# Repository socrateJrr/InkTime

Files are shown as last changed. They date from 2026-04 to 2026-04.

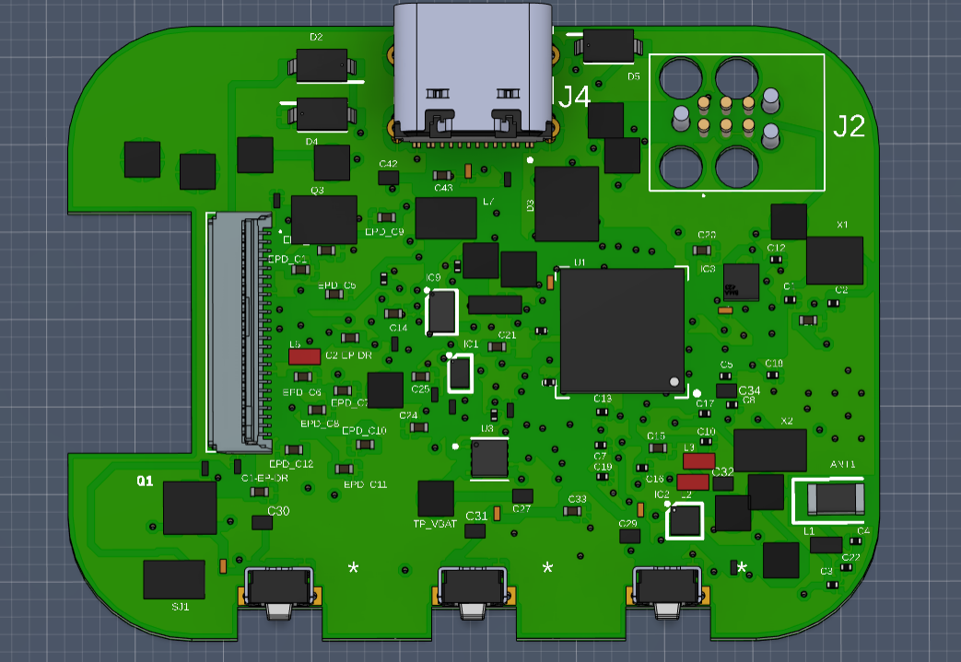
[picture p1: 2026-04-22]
Images/pcb2.png

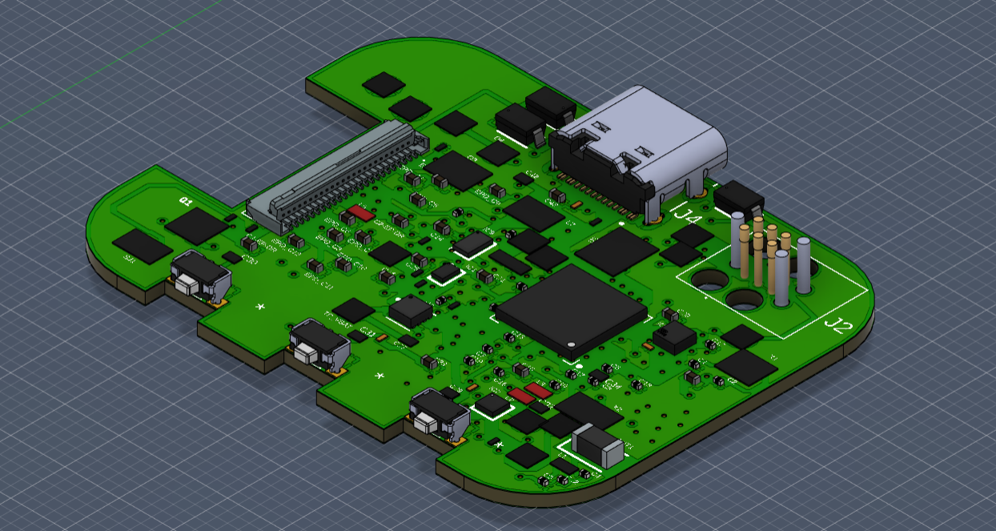
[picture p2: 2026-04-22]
Images/pcb1.png

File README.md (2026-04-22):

# InkTime Smartwatch — PCB Design

InkTime este un smartwatch open-source si low-cost, cu ecran e-paper.

## Diagrama bloc



## BOM (Bill of Materials)

| Referinta | Componenta | Descriere | JLC Parts | Datasheet |
| --- | --- | --- | --- | --- |
| U1 | nRF52840-QIAA | MCU principal BLE 5.0 | [JLC](https://jlcpcb.com/parts/componentSearch?searchTxt=nRF52840) | [Datasheet](https://infocenter.nordicsemi.com/pdf/nRF52840_PS_v1.7.pdf) |
| IC9 | RT6160AWSC | DC/DC Buck-Boost 3.3V | [JLC](https://jlcpcb.com/parts/componentSearch?searchTxt=RT6160AWSC) | [Datasheet](https://www.richtek.com/assets/product_file/RT6160A/DS6160A-00.pdf) |
| IC1 | BQ25180YBGR | LiPo Charger | [JLC](https://jlcpcb.com/parts/componentSearch?searchTxt=BQ25180) | [Datasheet](https://www.ti.com/lit/ds/symlink/bq25180.pdf) |
| U3 | MAX17048G+T10 | Fuel Gauge I2C | [JLC](https://jlcpcb.com/parts/componentSearch?searchTxt=MAX17048G) | [Datasheet](https://datasheets.maximintegrated.com/en/ds/MAX17048-MAX17049.pdf) |
| IC3 | BMA421 | IMU Accelerometru 3 axe | [JLC](https://jlcpcb.com/parts/componentSearch?searchTxt=BMA421) | [Datasheet](https://www.bosch-sensortec.com/media/boschsensortec/downloads/datasheets/bst-bma421-ds000.pdf) |
| IC2 | DRV2605YZFR | Haptic Driver I2C | [JLC](https://jlcpcb.com/parts/componentSearch?searchTxt=DRV2605) | [Datasheet](https://www.ti.com/lit/ds/symlink/drv2605.pdf) |
| ANT1 | 2450AT18B100E | Antena Bluetooth 2.4GHz | [JLC](https://jlcpcb.com/parts/componentSearch?searchTxt=2450AT18B100E) | [Datasheet](https://www.johansontechnology.com/datasheets/2450AT18B100E/2450AT18B100E.pdf) |
| J1 | 503480-2400 | Conector display e-paper 24 pini | [JLC](https://jlcpcb.com/parts/componentSearch?searchTxt=503480-2400) | [Datasheet](https://www.molex.com/pdm_docs/sd/5034802400_sd.pdf) |
| J4 | KH-TYPE-C-16P | Conector USB-C 16 pini | [JLC](https://jlcpcb.com/parts/componentSearch?searchTxt=KH-TYPE-C-16P) | - |
| D3 | USBLC6-2SC6Y | Protectie ESD USB | [JLC](https://jlcpcb.com/parts/componentSearch?searchTxt=USBLC6-2SC6Y) | [Datasheet](https://www.st.com/resource/en/datasheet/usblc6-2.pdf) |
| D2, D4, D5 | MBR0530 | Dioda Schottky | [JLC](https://jlcpcb.com/parts/componentSearch?searchTxt=MBR0530) | [Datasheet](https://www.onsemi.com/pdf/datasheet/mbr0530-d.pdf) |
| J2 | TC2030-IDC | Conector SWD Tag-Connect | [JLC](https://jlcpcb.com/parts/componentSearch?searchTxt=TC2030) | [Datasheet](https://www.tag-connect.com/wp-content/uploads/bsk-pdf-manager/TC2030-IDC_1.pdf) |
| X1 | Crystal 32MHz | Cristal principal MCU | [JLC](https://jlcpcb.com/parts/componentSearch?searchTxt=32MHz+crystal+3225) | - |
| X2 | Crystal 32.768kHz | Cristal RTC | [JLC](https://jlcpcb.com/parts/componentSearch?searchTxt=32768+crystal) | - |
| L7 | FTC252012SR47MBCA | Inductor 0.47uH DC/DC | [JLC](https://jlcpcb.com/parts/componentSearch?searchTxt=FTC252012SR47) | - |
| L5 | Inductor 68uH | Inductor e-paper drive | [JLC](https://jlcpcb.com/parts/componentSearch?searchTxt=68uH+inductor) | - |
| L1 | Inductor 3.9nH | Inductor RF matching | [JLC](https://jlcpcb.com/parts/componentSearch?searchTxt=3.9nH+inductor) | - |
| L2 | Inductor 15nH | Inductor RF | [JLC](https://jlcpcb.com/parts/componentSearch?searchTxt=15nH+inductor) | - |
| L3 | Inductor 10uH | Inductor DC/DC | [JLC](https://jlcpcb.com/parts/componentSearch?searchTxt=10uH+inductor+0402) | - |
| Q1 | DMG2305UX-7 | MOSFET P-channel e-paper | [JLC](https://jlcpcb.com/parts/componentSearch?searchTxt=DMG2305UX) | [Datasheet](https://www.diodes.com/assets/Datasheets/DMG2305UX.pdf) |
| Q3 | SI1308EDL-T1-GE3 | MOSFET N-channel e-paper | [JLC](https://jlcpcb.com/parts/componentSearch?searchTxt=SI1308EDL) | [Datasheet](https://www.vishay.com/docs/71509/si1308edl.pdf) |
| SW_UP/DN/ENT | Butoane tactile SMD | 3 butoane fizice | [JLC](https://jlcpcb.com/parts/componentSearch?searchTxt=tactile+button+smd) | - |
| R*, C* | Rezistente/Condensatoare | Diverse valori pasive | [JLC](https://jlcpcb.com/parts) | - |

---

## Descrierea functionalitatii hardware

### Microcontroller — nRF52840 (U1)

Nucleul dispozitivului este **nRF52840** de la Nordic Semiconductor, un SoC cu procesor ARM Cortex-M4 la 64MHz si BLE 5.0 integrat. Acesta coordoneaza toate perifericele prin interfetele SPI, I2C si GPIO.

Antena externa **ANT1** (2450AT18B100E) este o antena ceramica de 2.4GHz plasata la marginea dreapta a placii. Sub antena exista un decupaj in PCB pentru a maximiza performanta RF — FR4-ul absoarbe semnalul daca antena sta direct pe el. Circuitul de adaptare RF include inductorii L1 (3.9nH), L2 (15nH) si condensatoarele C3, C4, C22.

**Interfete folosite:**

- **SPI** → display e-paper (J1): MOSI, SCK, CS, DC, RST, BUSY
- **I2C** → IMU (IC3), charger (IC1), haptic (IC2), fuel gauge (U3), DC/DC (IC9)
- **USB** → D+/D- prin protectie ESD D3
- **SWD** → programare/debug prin J2 (TC2030-IDC)
- **GPIO** → butoane, intreruperi IMU, HAPTIC_EN

### Alimentare

**IC1 (BQ25180YBGR)** — charger LiPo care preia alimentarea de la USB-C si incarca bateria. Comunica cu MCU prin I2C pentru statusul incarcarii.

**IC9 (RT6160AWSC)** — DC/DC buck-boost converter care genereaza **3.3V stabil** din tensiunea bateriei (3V–4.2V). Inductorul L7 (0.47uH) face parte din circuitul de comutare. Condensatoarele C23, C24 filtreaza intrarea si C25, C33 iesirea.

**U3 (MAX17048G+T10)** — fuel gauge care monitorizeaza nivelul bateriei prin I2C si trimite o intrerupere (ALERT) la nRF cand bateria scade sub un prag configurat.

Bateria se conecteaza direct la test pad-urile **TP_VBAT** si **TP_BAT_GND** (fara conector JST) pentru economisire de spatiu.

### Display e-paper — J1 (503480-2400)

Conector FFC ZIF cu 24 de pini. Circuitul de drive include Q3, Q1, L5 (68uH), D2, D4, D5 si condensatoarele EPD_C1...C12. Comunicatie prin **SPI** + GPIO de control.

### IMU — BMA421 (IC3)

Accelerometru triaxial Bosch conectat prin **I2C**. Folosit pentru wake-on-wrist, pedometru si detectie orientare. Intreruperile IMU_INT1/INT2 sunt conectate la GPIO-uri dedicate ale nRF.

### Haptic — DRV2605YZFR (IC2)

Driver de motor haptic controlat prin **I2C**, activat prin **HAPTIC_EN**. Suporta efecte LRA si ERM din biblioteca interna de 123 efecte.

### USB-C — KH-TYPE-C-16P (J4)

Conector USB-C cu protectie ESD asigurata de D3 (USBLC6-2SC6Y). R1_USB si R2_USB (5K1) pe pinii CC1/CC2 pentru detectia cablului USB.

### Programare SWD — TC2030-IDC (J2)

Conector Tag-Connect 6 pini pentru programare si debug SWD. Semnale: SWDIO, SWDCLK, RESET, SWO, 3.3V, GND.

---

## Pinii nRF52840 folositi

| Pin nRF52840  | Semnal | Componenta | Functie |
| --- | --- | --- | --- |
| P0.00 (XL1) | XL1 | X1 (32MHz) | Cristal principal — clock MCU |
| P0.01 (XL2) | XL2 | X1 (32MHz) | Cristal principal — clock MCU |
| P0.26 | SCL | IC3, IC1, IC2, U3, IC9 | I2C clock |
| P0.27 | SDA | IC3, IC1, IC2, U3, IC9 | I2C data |
| P0.13 | D- | J4 via D3 | USB Data minus |
| P0.14 | D+ | J4 via D3 | USB Data plus |
| P0.17 | EPD_RST | J1 | Reset display e-paper |
| P0.18 (RESET) | RESET | J2 | Reset MCU via SWD |
| P0.19 | EPD_BUSY  | J1 | Status display e-paper |
| P0.20 | EPD_DC | J1 | Data/Command display |
| P0.21 | EPD_CS | J1 | Chip select display SPI |
| P0.22 | SCK | J1 | SPI clock display |
| P0.23 | MOSI | J1 | SPI data display |
| P0.24 | SWDCLK | J2 | SWD clock programare |
| P0.25 | SWDIO | J2 | SWD data programare |
| P1.01 | HAPTIC_EN | IC2 | Enable haptic driver |
| P1.02 | PMIC_INT  | IC1 | Intrerupere charger |
| P1.03 | IMU_INT1  | IC3 | Intrerupere IMU 1 |
| P1.04 | IMU_INT2  | IC3 | Intrerupere IMU 2 |
| P1.05 | SW_UP | SW_UP | Buton sus |
| P1.06 | SW_ENT | SW_ENT | Buton enter |
| P1.07 | SW_DN | SW_DN | Buton jos |
| ANT | RF | ANT1 | Antena Bluetooth 2.4GHz |
| VBUS | VBUS | J4 | Detectie USB conectat |
| DEC3V3 | 3V3 | IC9 output | Alimentare 3.3V |

---

## Structura PCB

**Dimensiuni:** 46mm x 35mm, grosime 1mm
**Straturi:** 4 (Top + GND + Power + Bottom)

| Strat | Continut | Latime trasee |
| --- | --- | --- |
| Top | Componente SMD + semnale date | min 0.15mm |
| GND (interior) | Plan de masa complet | - |
| Power (interior) | Trasee 3V3, VBAT, VBUS, VREG | 0.3mm |
| Bottom | Semnale suplimentare + plan GND | min 0.15mm |

Toate componentele sunt plasate exclusiv pe stratul **TOP**.

---

## Decizii de design

**Alegerea 4 straturi**
S-a optat pentru 4 straturi datorita densitatii mari de componente si numarului mare de semnale. Stratul interior Power permite rutarea traseelor de alimentare (3V3, VBAT, VBUS) separat de semnale.

**Conectarea GND prin Copper Pour**
Pinii de GND nu au fost conectati manual prin trasee individuale.
In schimb, s-au realizat planuri de masa (copper pour GND) pe straturile
Top, GND interior si Bottom. Prin refill-ul poligoanelor, toate padurile
de GND se conecteaza automat la planul de cupru, eliminand necesitatea
airwires-urilor individuale de GND.

## Erori DRC acceptate

- **Board Outline Clearance (~40 erori)** — cauzate de plasarea butoanelor si mufei USB conform specificatiilor mecanice. Neglijate conform enuntului proiectului.
- **"Only INPUT pins on NET ID"** — ignorata conform indicatiilor din enunt.
- **Erori de Dimension la butoane si USB** — neglijate conform enuntului.
- **Overlap-uri** — in anumite zone foarte aglomerate ale PCB-ului, rutarea semnalelor nu a putut evita complet apropierea de pinii vecini fara a intrerupe conexiunile necesare. S-a acceptat un numar mic de overlap-uri in aceste zone.
- **Fisierul `.fbrd` de referinta furnizat continea deja ~46 de erori DRC** din cauza formei si constructiei componentelor. Acestea nu au putut fi eliminate deoarece tin de geometria placii impuse.

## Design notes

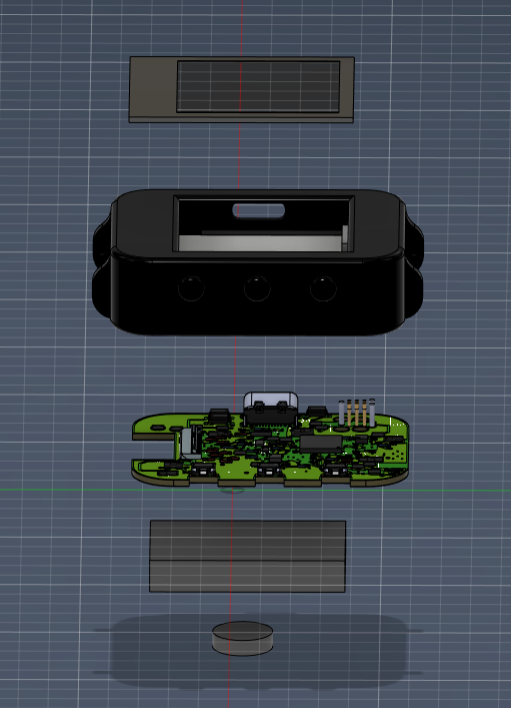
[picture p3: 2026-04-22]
Images/exploded2.png

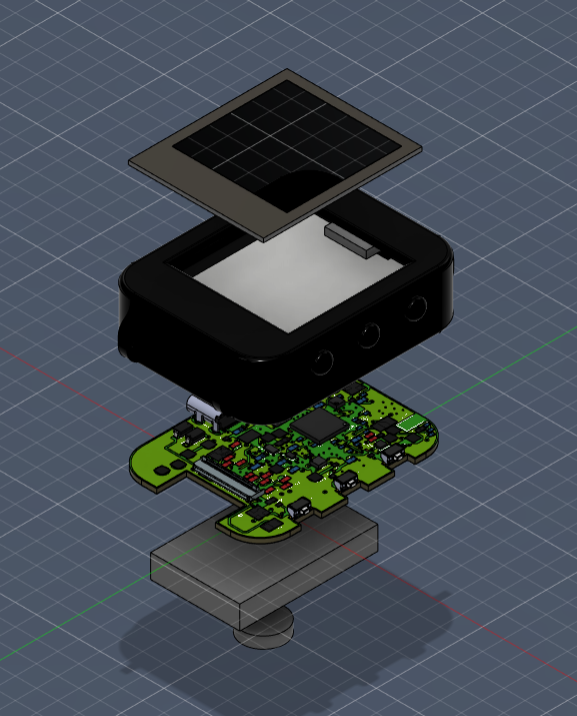
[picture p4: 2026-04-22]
Images/exploded1.png

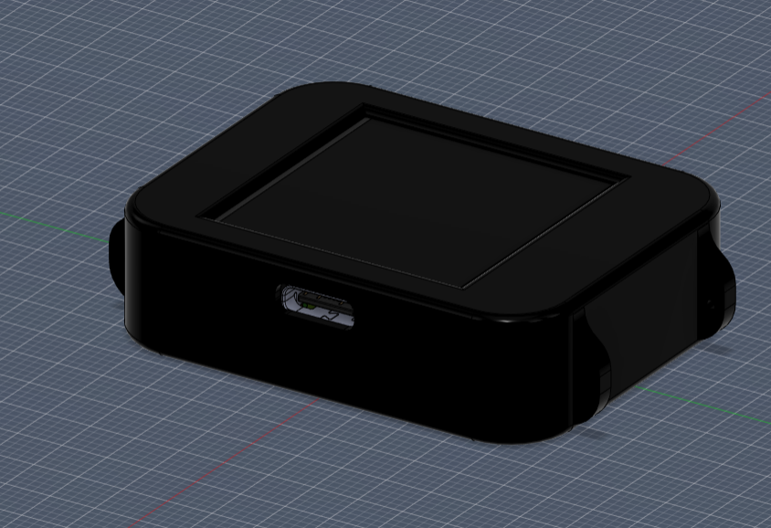
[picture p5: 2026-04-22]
Images/all1.png

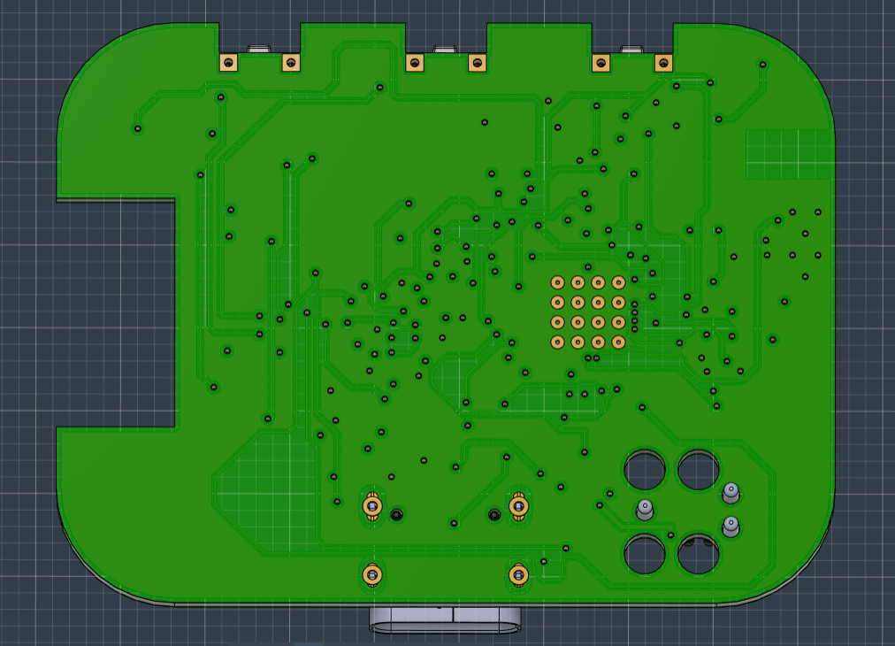
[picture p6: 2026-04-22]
Images/pcb3.png

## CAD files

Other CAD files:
Mechanical/InkTime_Exploded.step

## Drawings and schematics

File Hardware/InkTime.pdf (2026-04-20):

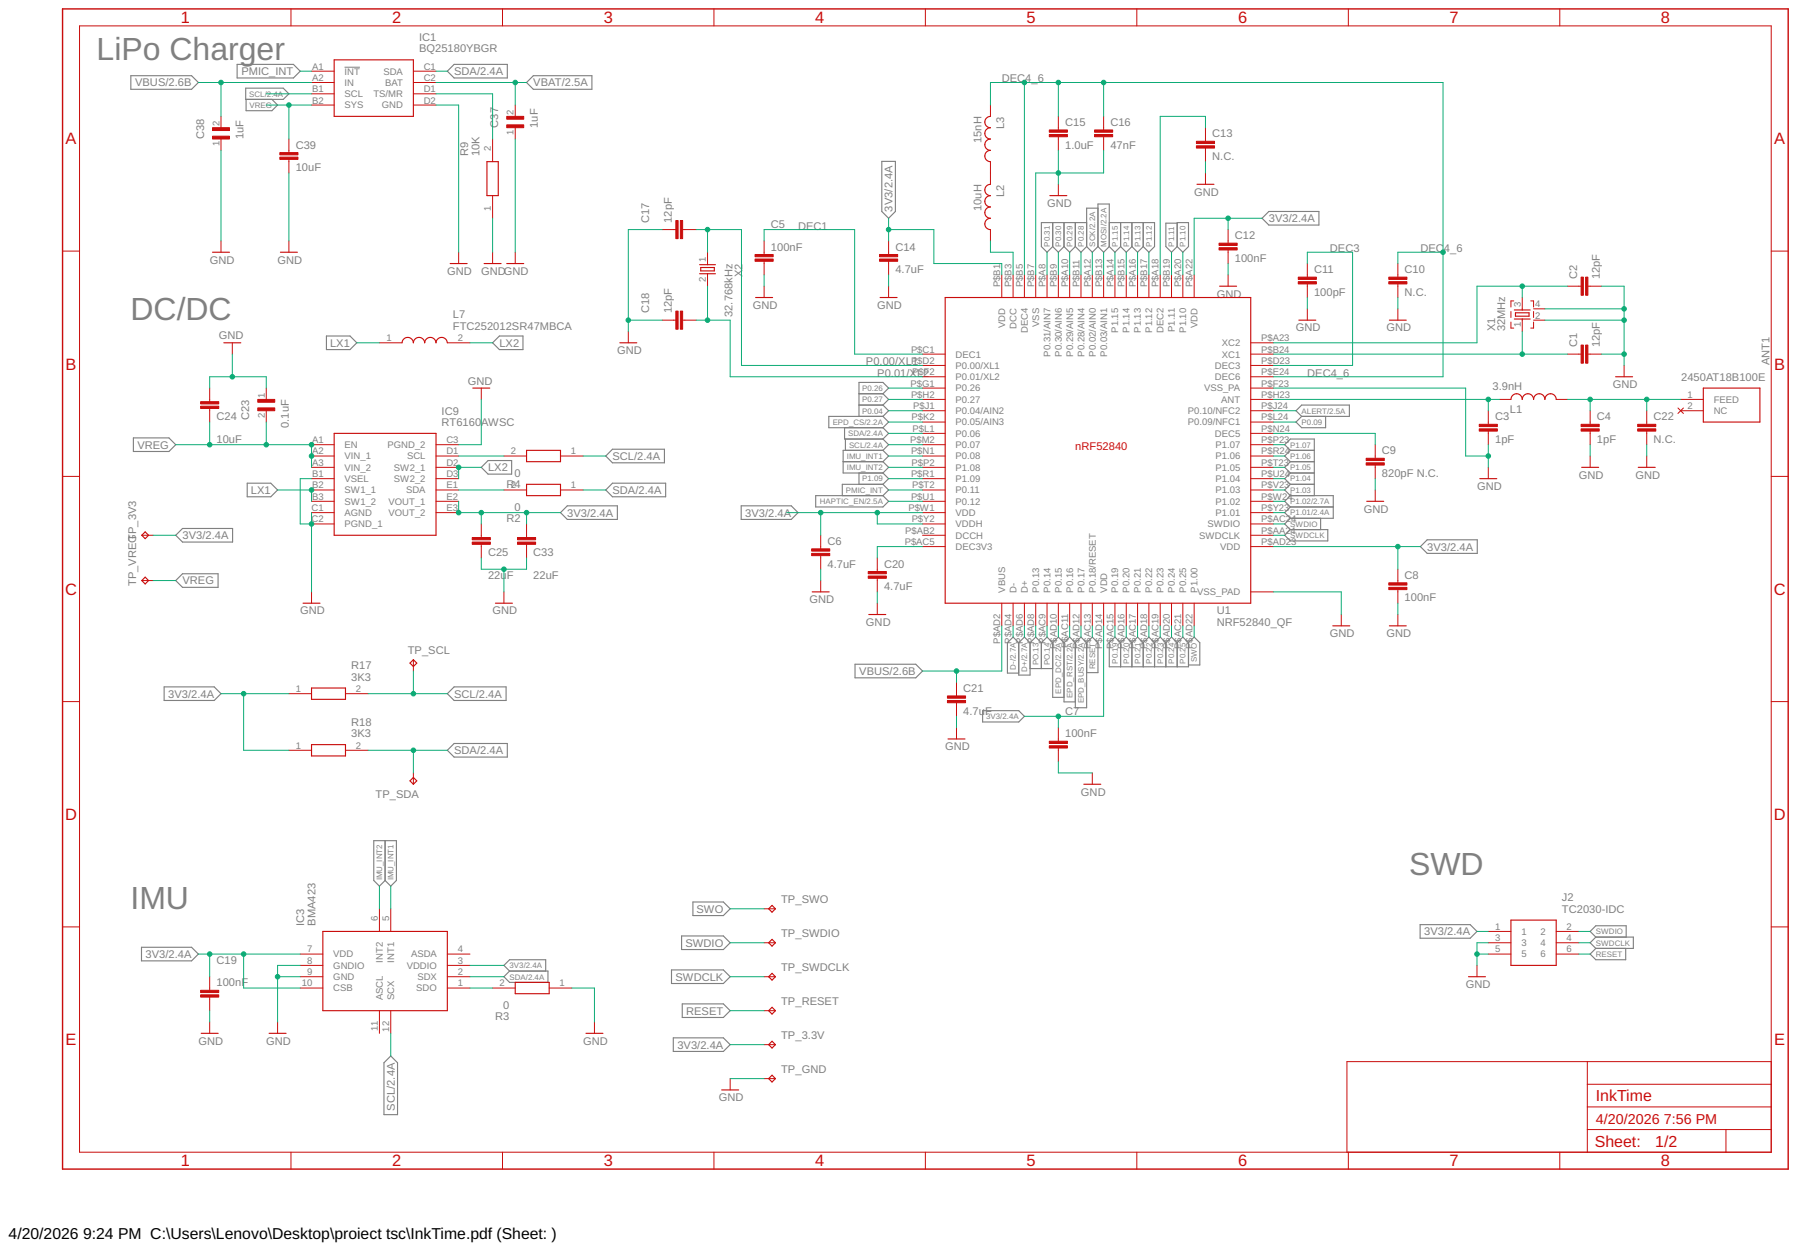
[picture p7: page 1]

4/20/2026 9:24 PM C:\Users\Lenovo\Desktop\proiect tsc\InkTime.pdf (Sheet: )

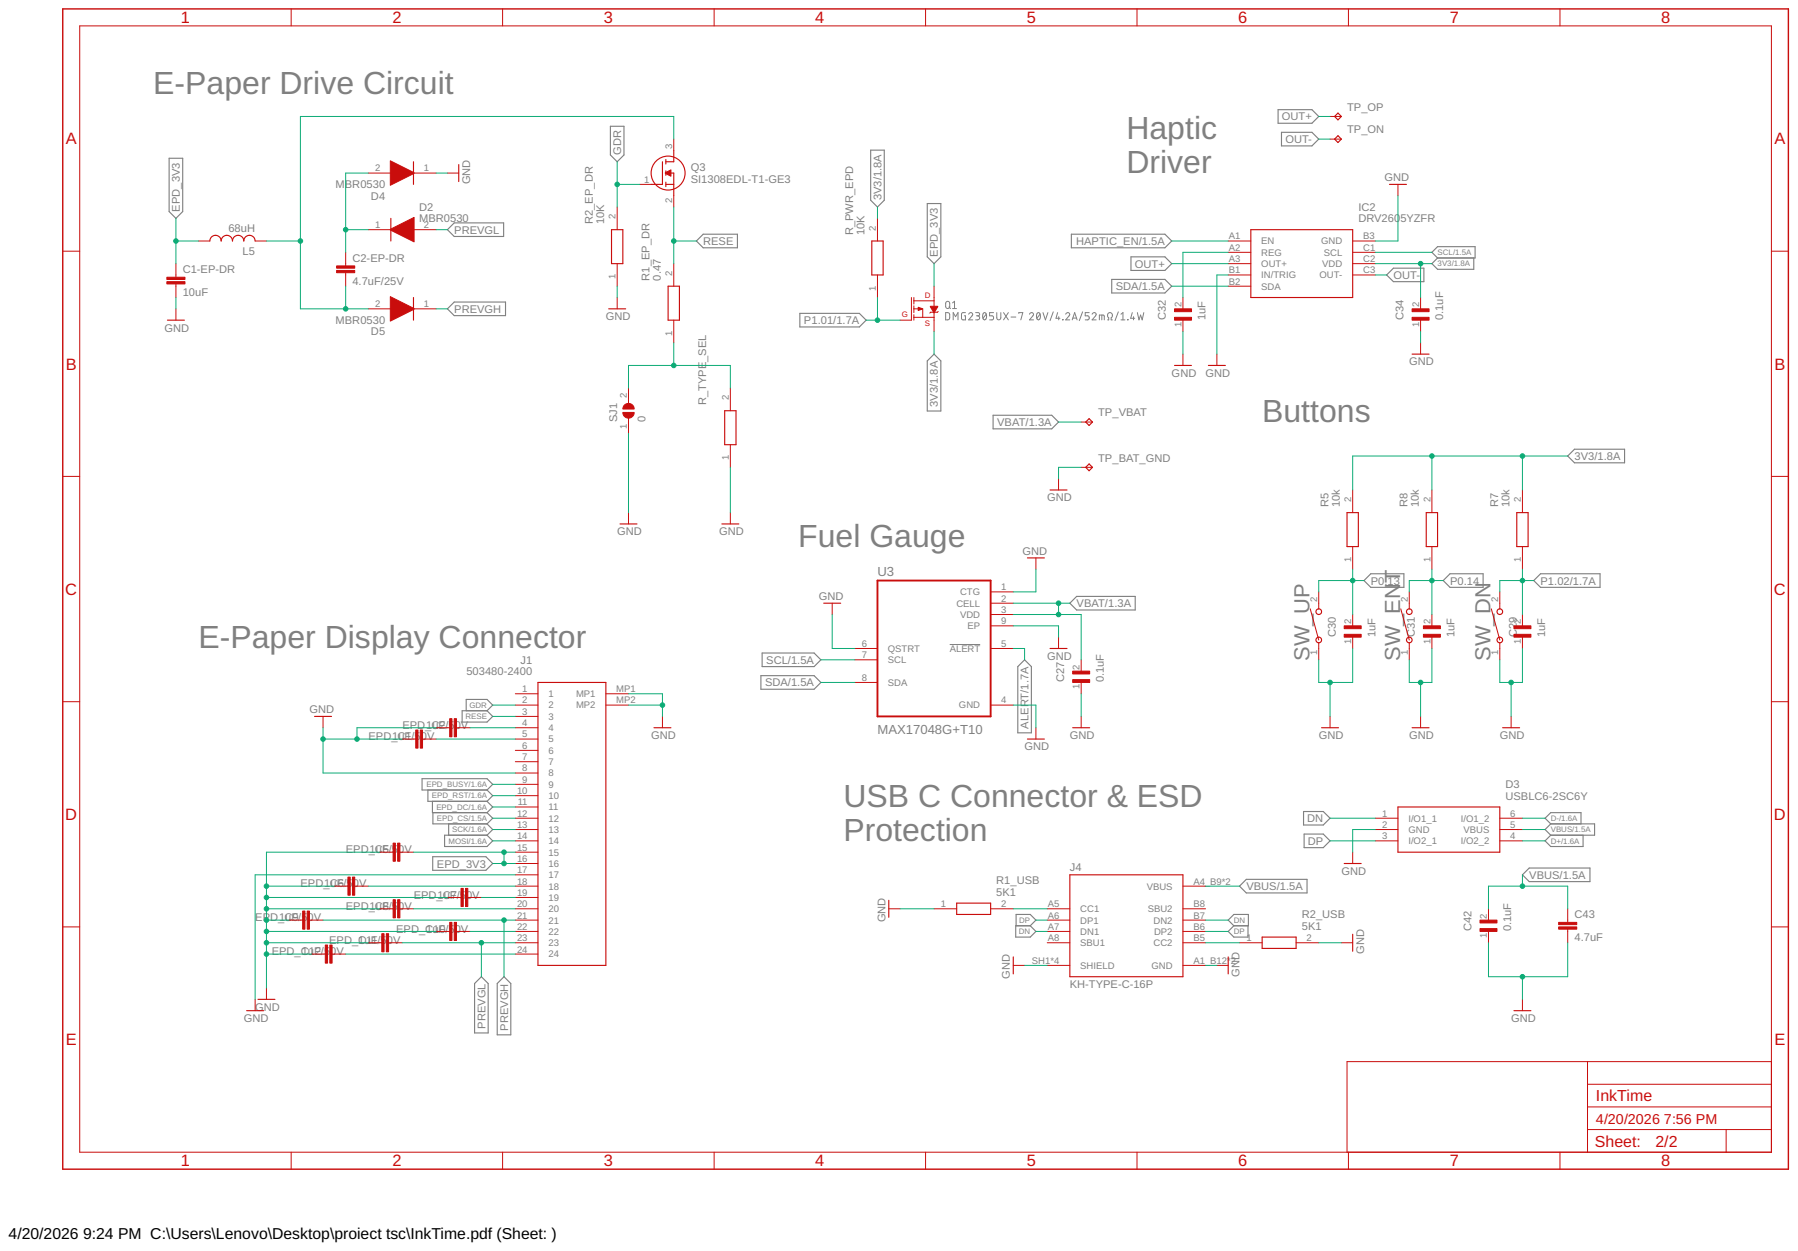
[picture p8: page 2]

EPD_C7 1uF/50V | 19

EPD_C8 1uF/50V | | 20

EPD_C10 1uF/50V | 22

EPD_C11 1uF/50V | | 23

4/20/2026 9:24 PM C:\Users\Lenovo\Desktop\proiect tsc\InkTime.pdf (Sheet: )

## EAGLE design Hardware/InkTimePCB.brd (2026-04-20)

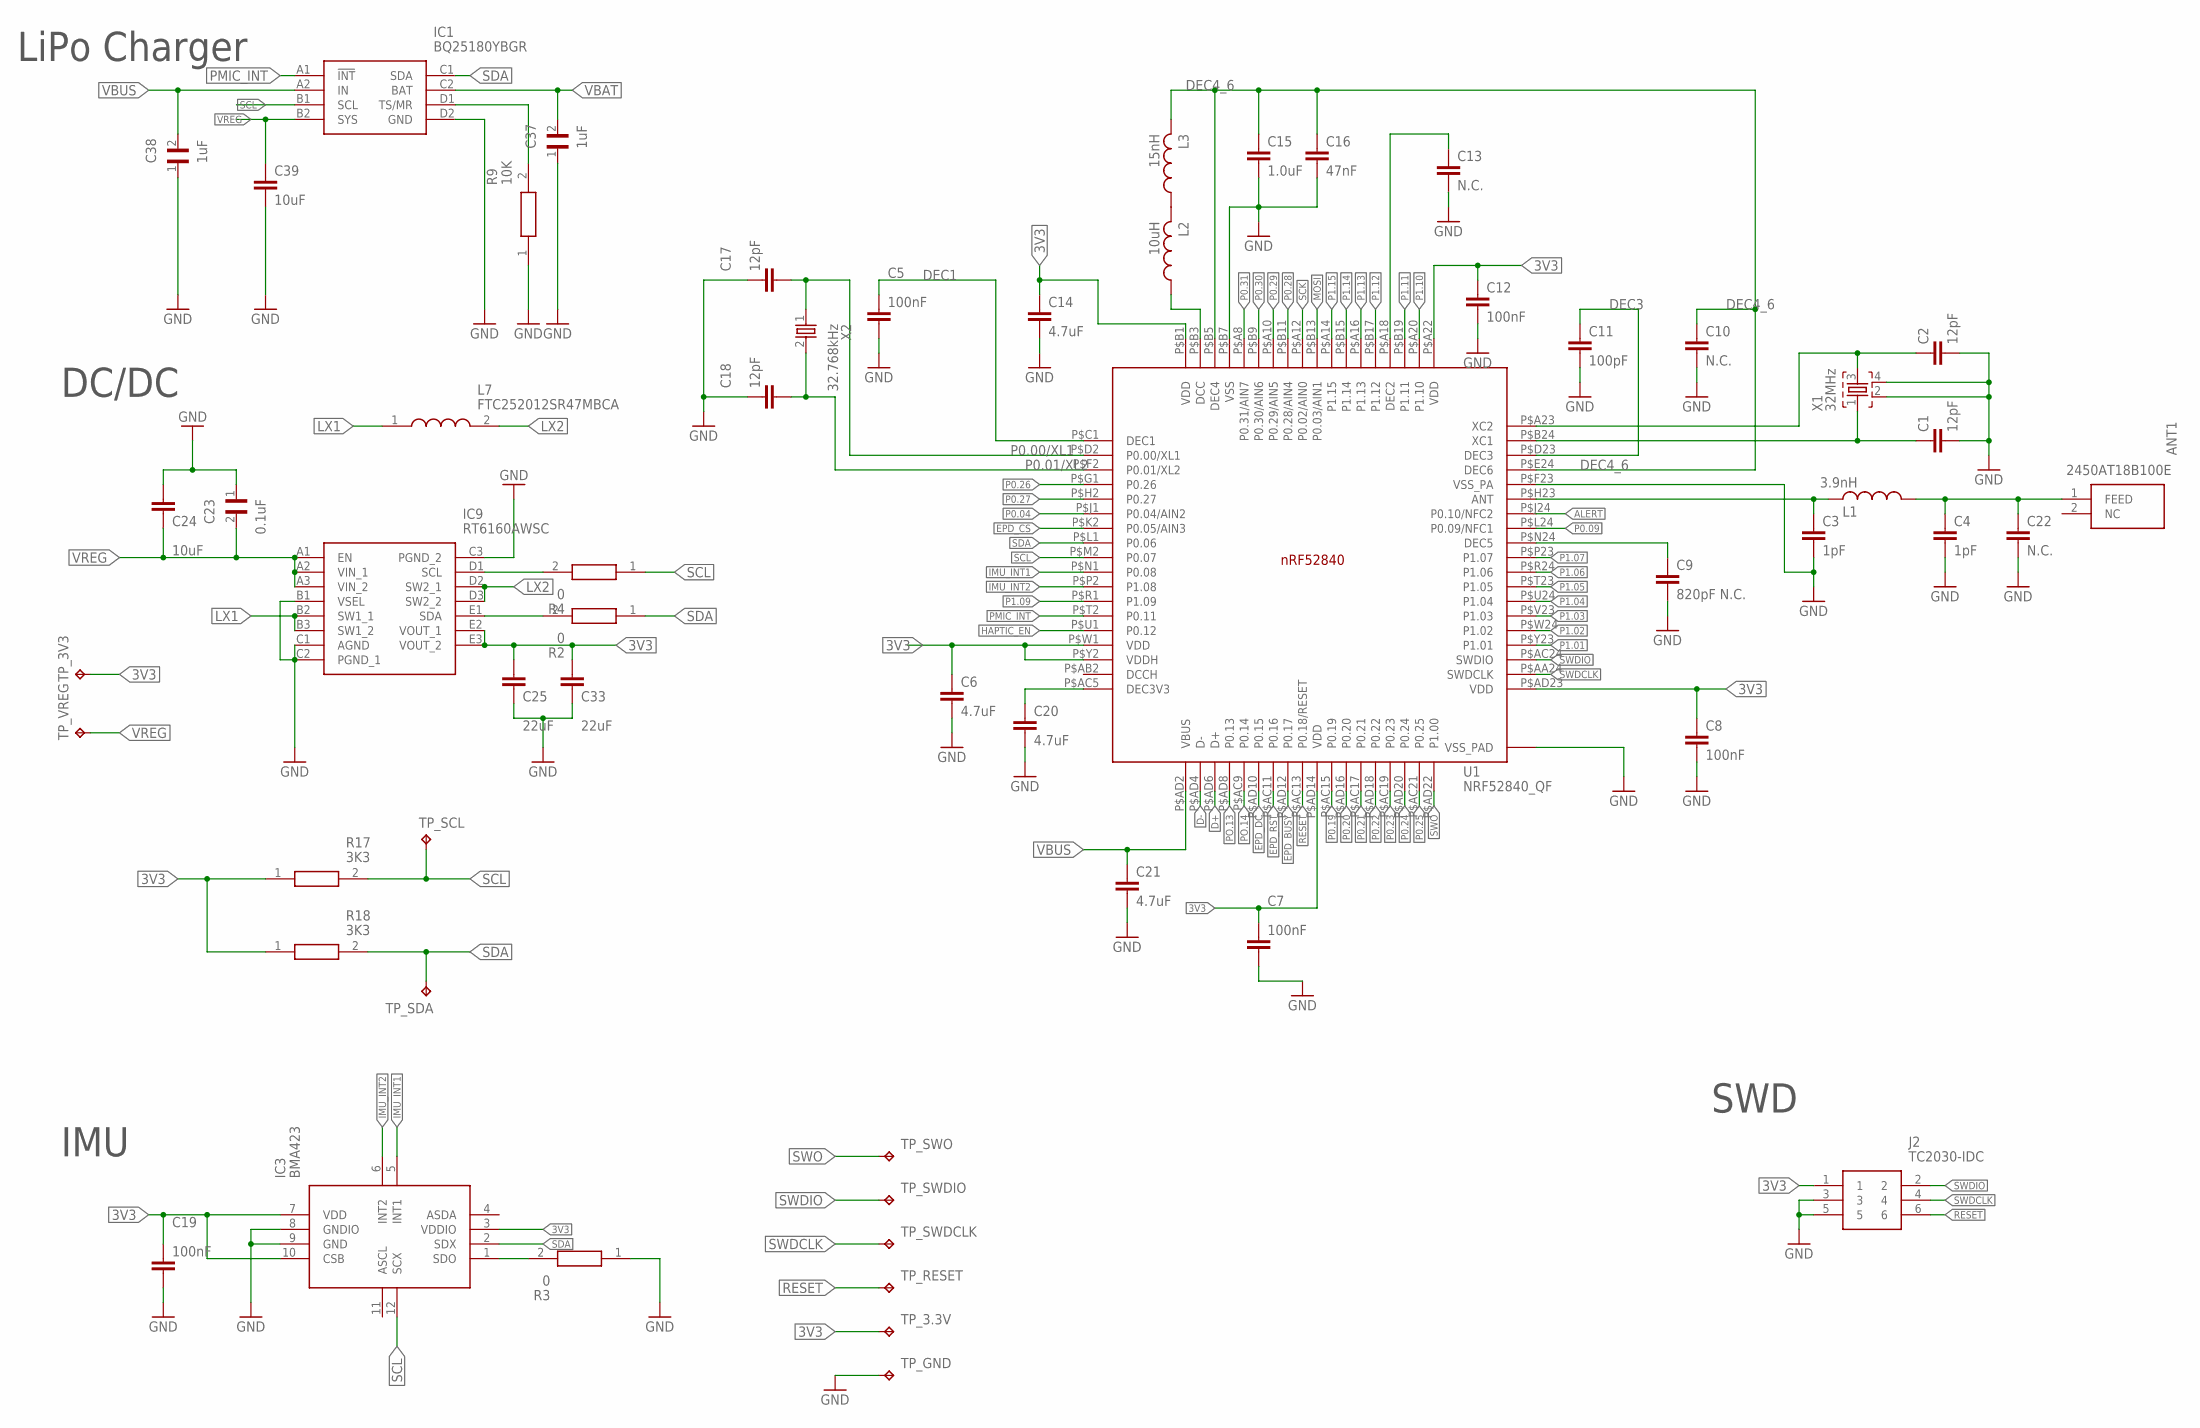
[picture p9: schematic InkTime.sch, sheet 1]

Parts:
ANT1: 2450AT18B100E; 2450AT18B100E_ANTC3216X140N
C1, C2, C17, C18: 12pF; NORDIC_NRF_3_RESC0201_L
C3, C4: 1pF; NORDIC_NRF_3_RESC0201_L
C5, C7, C8, C12, C19: 100nF; NORDIC_NRF_3_RESC0201_L
C6, C14, C20, C21: 4.7uF; PERFECT_0402_0402
C9: 820pF N.C.; NORDIC_NRF_3_RESC0201_L
C10, C13, C22: N.C.; NORDIC_NRF_3_RESC0201_L
C11: 100pF; NORDIC_NRF_3_RESC0201_L
C15: 1.0uF; PERFECT_0402_0402
C16: 47nF; NORDIC_NRF_3_RESC0201_L
C23: 0.1uF; GRM011R60J152KE01L_1_0201
C24: 10uF; PERFECT_0402_0402
C25, C33: 22uF; PERFECT_0402_0402
C37, C38: 1uF; GRM011R60J152KE01L_1_0201
C39: 10uF; ESP32_C6_LIBRARY_1_ESP32_WROVER_EAGLE-LTSPICE_C0402
IC1: BQ25180YBGR; BQ25180YBGR_BGA8C40P2X4_100X155X50
IC3: BMA423; BMA423_BMA423
IC9: RT6160AWSC; RT6160AWSC_BGA15C40P3X5_140X230X60
J2: TC2030-IDC; TC2030-IDC_TC2030IDC
L1: 3.9nH; NORDIC_NRF_2_RESC0402_L
L2: 10uH; NORDIC_NRF_2_RESC0402_L
L3: 15nH; NORDIC_NRF_2_RESC0402_L
L7: FTC252012SR47MBCA; MLP2016SR47MT0S1_INDC2016X100N
R2, R4: 0; ERA-1AEB3401C_0201
R3: 0; CPF0201D7K68C1_0201
R9: 10K; ERA-1AEB3401C_0201
R17, R18: 3K3; ERA-1AEB3401C_0201
TP_3.3V, TP_3V3: HECTOR_WATCH_1_TPTP20R; HECTOR_WATCH_1_TP20R
TP_GND: HECTOR_WATCH_1_TPTP20R; HECTOR_WATCH_1_TP20R
TP_RESET: HECTOR_WATCH_1_TPTP20R; HECTOR_WATCH_1_TP20R
TP_SCL: HECTOR_WATCH_1_TPTP20R; HECTOR_WATCH_1_TP20R
TP_SDA: HECTOR_WATCH_1_TPTP20R; HECTOR_WATCH_1_TP20R
TP_SWDCLK: HECTOR_WATCH_1_TPTP20R; HECTOR_WATCH_1_TP20R
TP_SWDIO: HECTOR_WATCH_1_TPTP20R; HECTOR_WATCH_1_TP20R
TP_SWO: HECTOR_WATCH_1_TPTP20R; HECTOR_WATCH_1_TP20R
TP_VREG: HECTOR_WATCH_1_TPTP20R; HECTOR_WATCH_1_TP20R
U1: NRF52840_QF; NORDIC_NRF_4_AQFN50P700X700X85_HS-74N
X1: 32MHz; NORDIC_NRF_BT-XTAL_2016_N
X2: 32.768kHz; NORDIC_NRF_1_XTAL_3215_N

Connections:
3V3: C6.1, C7.1, C8.1, C12.1, C14.1, C19.1, C25.1, C33.1, IC3.3 (VDDIO), IC3.7 (VDD), IC3.10 (CSB), IC9.E2 (VOUT_1), IC9.E3 (VOUT_2), J2.1, R17.1, R18.1, TP_3.3V.TP, TP_3V3.TP, U1.P$A22 (VDD), U1.P$AD14 (VDD), U1.P$AD23 (VDD), U1.P$B1 (VDD), U1.P$W1 (VDD), U1.P$Y2 (VDDH); also elsewhere on the board
ALERT: U1.P$J24 (P0.10/NFC2); also elsewhere on the board
D+: U1.P$AD6 (D+); also elsewhere on the board
D-: U1.P$AD4 (D-); also elsewhere on the board
DEC1: C5.1, U1.P$C1 (DEC1)
DEC3: C11.1, U1.P$D23 (DEC3)
DEC4_6: C10.1, C15.1, C16.1, L3.2, U1.P$B5 (DEC4), U1.P$E24 (DEC6)
EPD_BUSY: U1.P$AD12 (P0.17); also elsewhere on the board
EPD_CS: U1.P$K2 (P0.05/AIN3); also elsewhere on the board
EPD_DC: U1.P$AD10 (P0.15); also elsewhere on the board
EPD_RST: U1.P$AC11 (P0.16); also elsewhere on the board
GND: C1.2, C2.2, C3.2, C4.2, C5.2, C6.2, C7.2, C8.2, C9.2, C10.2, C11.2, C12.2, C13.2, C14.2, C15.2, C16.2, C17.1, C18.1, C19.2, C20.2, C21.2, C22.2, C23.1, C24.1, C25.2, C33.2, C37.1, C38.1, C39.2, IC1.D2 (GND), IC3.8 (GNDIO), IC3.9 (GND), IC9.B1 (VSEL), IC9.C1 (AGND), IC9.C2 (PGND_1), IC9.C3 (PGND_2), J2.3, J2.5, R3.1, R9.1, TP_GND.TP, U1.P$74 (VSS_PAD), U1.P$75 (VSS_PAD), U1.P$76 (VSS_PAD), U1.P$77 (VSS_PAD), U1.P$78 (VSS_PAD), U1.P$79 (VSS_PAD), U1.P$80 (VSS_PAD), U1.P$81 (VSS_PAD), U1.P$82 (VSS_PAD), U1.P$83 (VSS_PAD), U1.P$84 (VSS_PAD), U1.P$85 (VSS_PAD), U1.P$86 (VSS_PAD), U1.P$87 (VSS_PAD), U1.P$88 (VSS_PAD), U1.P$89 (VSS_PAD), U1.P$90 (VSS_PAD), U1.P$B7 (VSS), U1.P$F23 (VSS_PA), X1.2, X1.4; also elsewhere on the board
HAPTIC_EN: U1.P$U1 (P0.12); also elsewhere on the board
IMU_INT1: IC3.5 (INT1), U1.P$N1 (P0.08)
IMU_INT2: IC3.6 (INT2), U1.P$P2 (P1.08)
LX1: IC9.B2 (SW1_1), IC9.B3 (SW1_2), L7.1
LX2: IC9.D2 (SW2_1), IC9.D3 (SW2_2), L7.2
MOSI: U1.P$B13 (P0.03/AIN1); also elsewhere on the board
unnamed: ANT1.1 (FEED), C4.1, C22.1, L1.2
unnamed: IC9.D1 (SCL), R4.2
unnamed: IC1.D1 (TS/MR), R9.2
unnamed: C2.1, U1.P$A23 (XC2), X1.3
unnamed: IC9.E1 (SDA), R2.2
unnamed: L2.2, L3.1
unnamed: IC3.1 (SDO), R3.2
unnamed: C1.1, U1.P$B24 (XC1), X1.1
unnamed: C3.1, L1.1, U1.P$H23 (ANT)
unnamed: C9.1, U1.P$N24 (DEC5)
unnamed: C20.1, U1.P$AC5 (DEC3V3)
unnamed: L2.1, U1.P$B3 (DCC)
unnamed: C13.1, U1.P$A18 (DEC2)
P0.00/XL1: C17.2, U1.P$D2 (P0.00/XL1), X2.1
P0.01/XL2: C18.2, U1.P$F2 (P0.01/XL2), X2.2
P0.04: U1.P$J1 (P0.04/AIN2)
P0.09: U1.P$L24 (P0.09/NFC1)
P0.19: U1.P$AC15 (P0.19)
P0.20: U1.P$AD16 (P0.20)
P0.21: U1.P$AC17 (P0.21)
P0.22: U1.P$AD18 (P0.22)
P0.23: U1.P$AC19 (P0.23)
P0.24: U1.P$AD20 (P0.24)
P0.25: U1.P$AC21 (P0.25)
P0.26: U1.P$G1 (P0.26)
P0.27: U1.P$H2 (P0.27)
P0.28: U1.P$B11 (P0.28/AIN4)
P0.29: U1.P$A10 (P0.29/AIN5)
P0.30: U1.P$B9 (P0.30/AIN6)
P0.31: U1.P$A8 (P0.31/AIN7)
P1.01: U1.P$Y23 (P1.01); also elsewhere on the board
P1.02: U1.P$W24 (P1.02); also elsewhere on the board
P1.03: U1.P$V23 (P1.03)
P1.04: U1.P$U24 (P1.04)
P1.05: U1.P$T23 (P1.05)
P1.06: U1.P$R24 (P1.06)
P1.07: U1.P$P23 (P1.07)
P1.09: U1.P$R1 (P1.09)
P1.10: U1.P$A20 (P1.10)
P1.11: U1.P$B19 (P1.11)
P1.12: U1.P$B17 (P1.12)
P1.13: U1.P$A16 (P1.13)
P1.14: U1.P$B15 (P1.14)
P1.15: U1.P$A14 (P1.15)
PMIC_INT: IC1.A1 (!INT), U1.P$T2 (P0.11)
PO.13: U1.P$AD8 (P0.13)
PO.14: U1.P$AC9 (P0.14)
RESET: J2.6, TP_RESET.TP, U1.P$AC13 (P0.18/RESET)
SCK: U1.P$A12 (P0.02/AIN0); also elsewhere on the board
SCL: IC1.B1 (SCL), IC3.12 (SCX), R4.1, R17.2, TP_SCL.TP, U1.P$M2 (P0.07); also elsewhere on the board
SDA: IC1.C1 (SDA), IC3.2 (SDX), R2.1, R18.2, TP_SDA.TP, U1.P$L1 (P0.06); also elsewhere on the board
SWDCLK: J2.4, TP_SWDCLK.TP, U1.P$AA24 (SWDCLK)
SWDIO: J2.2, TP_SWDIO.TP, U1.P$AC24 (SWDIO)
SWO: TP_SWO.TP, U1.P$AD22 (P1.00)
VBAT: C37.2, IC1.C2 (BAT); also elsewhere on the board
VBUS: C21.1, C38.2, IC1.A2 (IN), U1.P$AD2 (VBUS); also elsewhere on the board
VREG: C23.2, C24.2, C39.1, IC1.B2 (SYS), IC9.A1 (EN), IC9.A2 (VIN_1), IC9.A3 (VIN_2), TP_VREG.TP

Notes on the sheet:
LiPo Charger
DC/DC
IMU
SWD

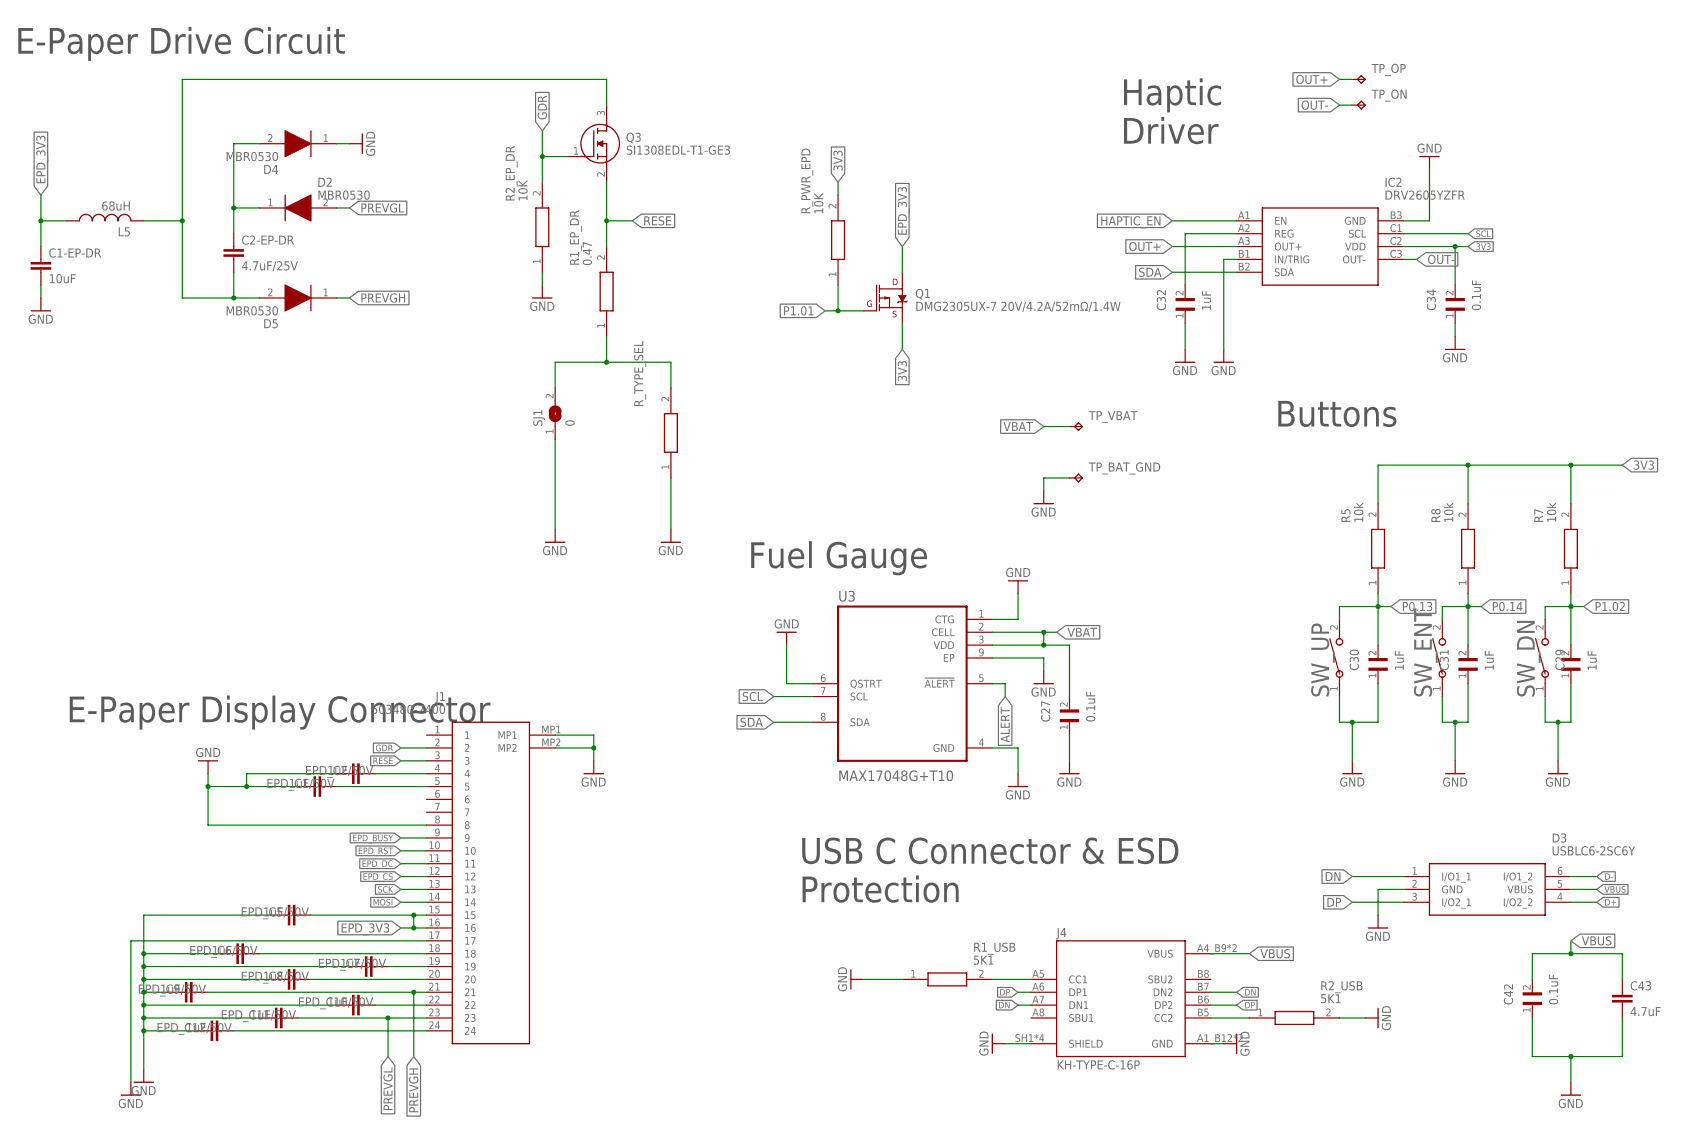
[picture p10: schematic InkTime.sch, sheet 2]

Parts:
C1-EP-DR: 10uF; PERFECT_0402_0402
C2-EP-DR: 4.7uF/25V; PERFECT_0402_0402
C27, C34, C42: 0.1uF; GRM011R60J152KE01L_2_CAPC0201X13N
C29, C30, C31, C32: 1uF; GRM011R60J152KE01L_2_CAPC0201X13N
C43: 4.7uF; PERFECT_0402_0402
D2, D4, D5: MBR0530; ESP32_C6_LIBRARY_5_SOD3716X135N
D3: USBLC6-2SC6Y; ESP32_C6_LIBRARY_3_SOT95P280X145-6N
EPD_C1, EPD_C2, EPD_C5, EPD_C6, EPD_C7, EPD_C8, EPD_C9, EPD_C10, EPD_C11, EPD_C12: 1uF/50V; PERFECT_0402_0402
IC2: DRV2605YZFR; DRV2605YZFR_BGA9C50P3X3_144X144X62
J1: 503480-2400; 503480-2400_5034802400
J4: KH-TYPE-C-16P; KH-TYPE-C-16P_KINGHELM_KH-TYPE-C-16P
L5: 68uH; NORDIC_NRF_2_RESC0402_L
Q1: DMG2305UX-7 20V/4.2A/52mΩ/1.4W; ESP32_C6_LIBRARY_4_ESP32_C6_LIBRARY_4_ESP32_C6_LIBRARY_4_ES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
Q3: SI1308EDL-T1-GE3; ESP32_C6_LIBRARY_6_SOT65P210X110-3N
R1_EP_DR: 0.47; ERA-1AEB3401C_0201
R1_USB, R2_USB: 5K1; CPF0201D7K68C1_0201
R2_EP_DR: 10K; ERA-1AEB3401C_0201
R5, R7, R8: 10k; CPF0201D7K68C1_0201
R_PWR_EPD: 10K; CPF0201D7K68C1_0201
R_TYPE_SEL: 2.2; ERA-1AEB3401C_0201
SJ1: 0; ESP32_C6_LIBRARY_7_JUMPER_SJ
SW_DN: 2025-10-22_07-23-44_LIBRARY_EVP-AKE31ASW_EVP-AKE3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; 2025-10-22_07-23-44_LIBRARY_SW_EVP-AKE31A_PAN
SW_ENT: 2025-10-22_07-23-44_LIBRARY_EVP-AKE31ASW_EVP-AKE3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; 2025-10-22_07-23-44_LIBRARY_SW_EVP-AKE31A_PAN
SW_UP: 2025-10-22_07-23-44_LIBRARY_EVP-AKE31ASW_EVP-AKE3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; 2025-10-22_07-23-44_LIBRARY_SW_EVP-AKE31A_PAN
TP_BAT_GND: HECTOR_WATCH_1_TPTP20R; HECTOR_WATCH_1_TP20R
TP_ON: HECTOR_WATCH_1_TPTP20R; HECTOR_WATCH_1_TP20R
TP_OP: HECTOR_WATCH_1_TPTP20R; HECTOR_WATCH_1_TP20R
TP_VBAT: HECTOR_WATCH_1_TPTP20R; HECTOR_WATCH_1_TP20R
U3: MAX17048G+T10; ESP32_C6_LIBRARY_SON50P200X200X80-9N

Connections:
3V3: C34.2, IC2.C2 (VDD), Q1.2 (S), R5.2, R7.2, R8.2, R_PWR_EPD.2; also elsewhere on the board
ALERT: U3.5 (!ALERT); also elsewhere on the board
D+: D3.4 (I/O2_2); also elsewhere on the board
D-: D3.6 (I/O1_2); also elsewhere on the board
DN: D3.1 (I/O1_1), J4.A7 (DN1), J4.B7 (DN2)
DP: D3.3 (I/O2_1), J4.A6 (DP1), J4.B6 (DP2)
EPD_3V3: C1-EP-DR.1, EPD_C5.2, J1.15, J1.16, L5.1, Q1.3 (D)
EPD_BUSY: J1.9; also elsewhere on the board
EPD_CS: J1.12; also elsewhere on the board
EPD_DC: J1.11; also elsewhere on the board
EPD_RST: J1.10; also elsewhere on the board
GDR: J1.2, Q3.1 (G), R2_EP_DR.2
GND: C1-EP-DR.2, C27.1, C29.1, C30.1, C31.1, C32.1, C34.1, C42.1, C43.2, D3.2 (GND), D4.1 (K), EPD_C1.1, EPD_C2.1, EPD_C5.1, EPD_C6.1, EPD_C7.1, EPD_C8.1, EPD_C9.1, EPD_C10.1, EPD_C11.1, EPD_C12.1, IC2.B1 (IN/TRIG), IC2.B3 (GND), J1.8, J1.17, J1.MP1, J1.MP2, J4.A1_B12 (GND), J4.A12_B1 (GND), J4.SH1 (SHIELD), J4.SH2 (SHIELD), J4.SH3 (SHIELD), J4.SH4 (SHIELD), R1_USB.1, R2_EP_DR.1, R2_USB.2, R_TYPE_SEL.1, SJ1.1, SW_DN.1, SW_ENT.1, SW_UP.1, TP_BAT_GND.TP, U3.1 (CTG), U3.4 (GND), U3.6 (QSTRT), U3.9 (EP); also elsewhere on the board
HAPTIC_EN: IC2.A1 (EN); also elsewhere on the board
MOSI: J1.14; also elsewhere on the board
unnamed: J4.A5 (CC1), R1_USB.2
unnamed: C32.2, IC2.A2 (REG)
unnamed: C2-EP-DR.1, D2.1 (K), D4.2 (A)
unnamed: R1_EP_DR.1, R_TYPE_SEL.2, SJ1.2
unnamed: C2-EP-DR.2, D5.2 (A), L5.2, Q3.3 (D)
unnamed: EPD_C2.2, J1.4
unnamed: EPD_C1.2, J1.5
unnamed: J4.B5 (CC2), R2_USB.1
unnamed: EPD_C6.2, J1.18
unnamed: EPD_C7.2, J1.19
unnamed: EPD_C8.2, J1.20
unnamed: EPD_C10.2, J1.22
unnamed: EPD_C12.2, J1.24
OUT+: IC2.A3 (OUT+), TP_OP.TP
OUT-: IC2.C3 (OUT-), TP_ON.TP
P0.13: C30.2, R5.1, SW_UP.2
P0.14: C31.2, R8.1, SW_ENT.2
P1.01: Q1.1 (G), R_PWR_EPD.1; also elsewhere on the board
P1.02: C29.2, R7.1, SW_DN.2; also elsewhere on the board
PREVGH: D5.1 (K), EPD_C9.2, J1.21
PREVGL: D2.2 (A), EPD_C11.2, J1.23
RESE: J1.3, Q3.2 (S), R1_EP_DR.2
SCK: J1.13; also elsewhere on the board
SCL: IC2.C1 (SCL), U3.7 (SCL); also elsewhere on the board
SDA: IC2.B2 (SDA), U3.8 (SDA); also elsewhere on the board
VBAT: C27.2, TP_VBAT.TP, U3.2 (CELL), U3.3 (VDD); also elsewhere on the board
VBUS: C42.2, C43.1, D3.5 (VBUS), J4.A4_B9 (VBUS), J4.A9_B4 (VBUS); also elsewhere on the board

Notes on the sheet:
E-Paper Drive Circuit
E-Paper Display Connector
Fuel Gauge
Haptic Driver
Buttons
USB C Connector & ESD Protection

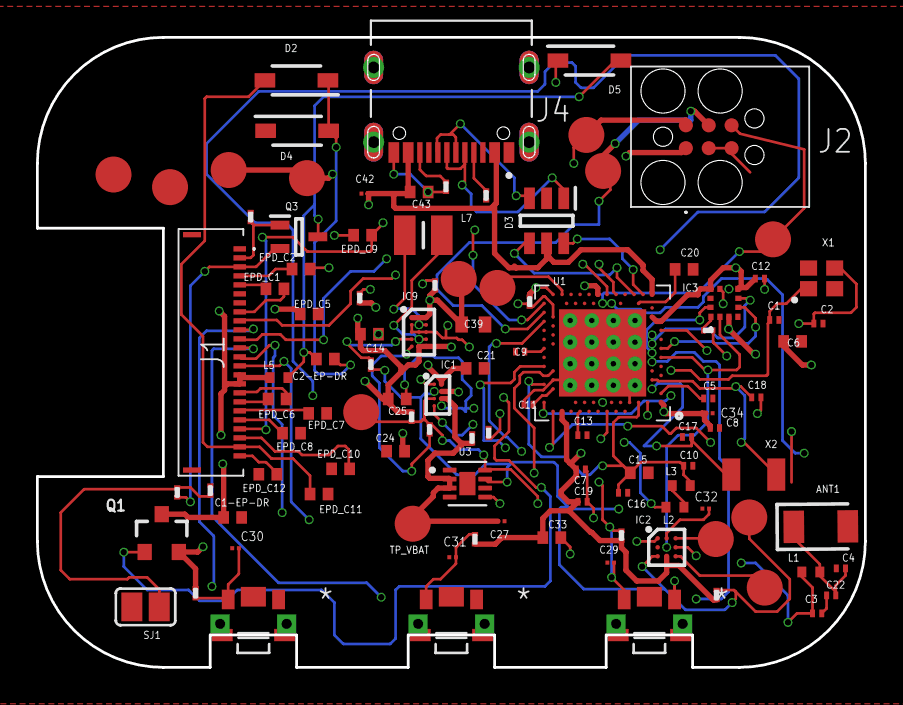
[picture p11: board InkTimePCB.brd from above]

Board: 4 copper layers, 46.0 x 35.0 mm, 105 parts (0 on the bottom side), 70 nets.

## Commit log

2026-04-10 Add README for InkTime smartwatch project
    Added project description and specifications for InkTime smartwatch PCB design.
2026-04-20 Add exploded view STEP file
    [exploded_view.step]
2026-04-22 Add InkTime exploded view
    [InkTime_Exploded.step]

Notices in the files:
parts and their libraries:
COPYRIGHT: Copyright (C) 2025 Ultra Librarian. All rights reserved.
